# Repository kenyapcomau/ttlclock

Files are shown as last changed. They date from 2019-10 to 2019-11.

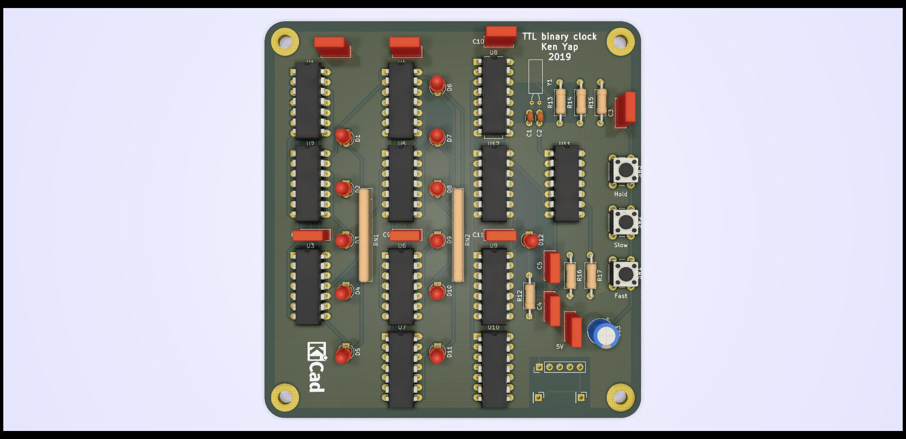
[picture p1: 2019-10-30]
ttlclock-raytraced.jpg

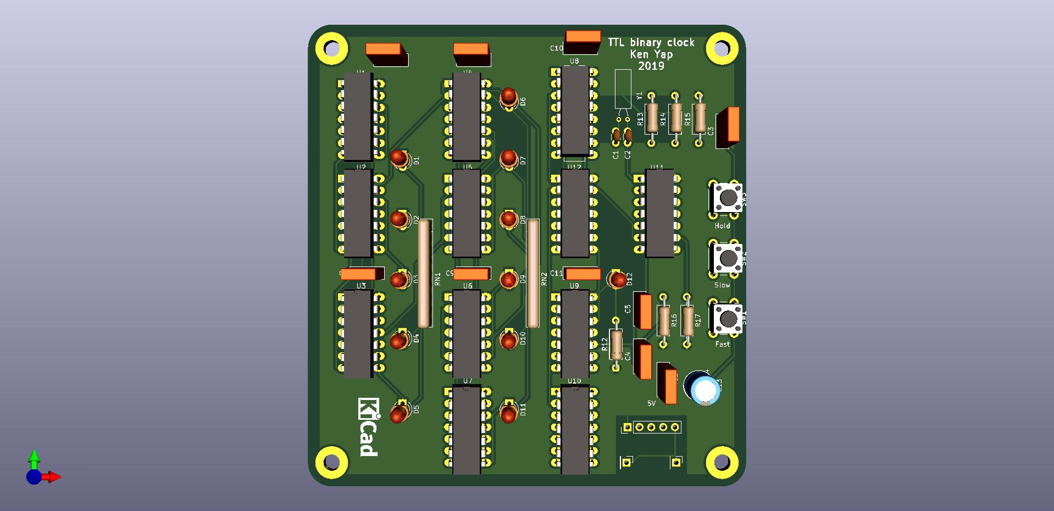
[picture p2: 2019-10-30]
ttlclock.jpg

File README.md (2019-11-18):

# TTL clock

These are the Kicad design files for the TTL clock described in my [Hackaday project](https://hackaday.io/project/168157-ttl-binary-clock)

## Versioning

First release November 2019

## Notes

Due to the 2 LS load fan out of the CD4060 (U8), you should use a 74LS50 (U12) and not a standard TTL package, otherwise the 1 Hz signal will be unreliable. Anyway non-LS parts are rare these days. LS is lower power consumption too.

## Authors

* **Ken Yap**

## License

See the [LICENSE](LICENSE.md) file for license rights and limitations (MIT).

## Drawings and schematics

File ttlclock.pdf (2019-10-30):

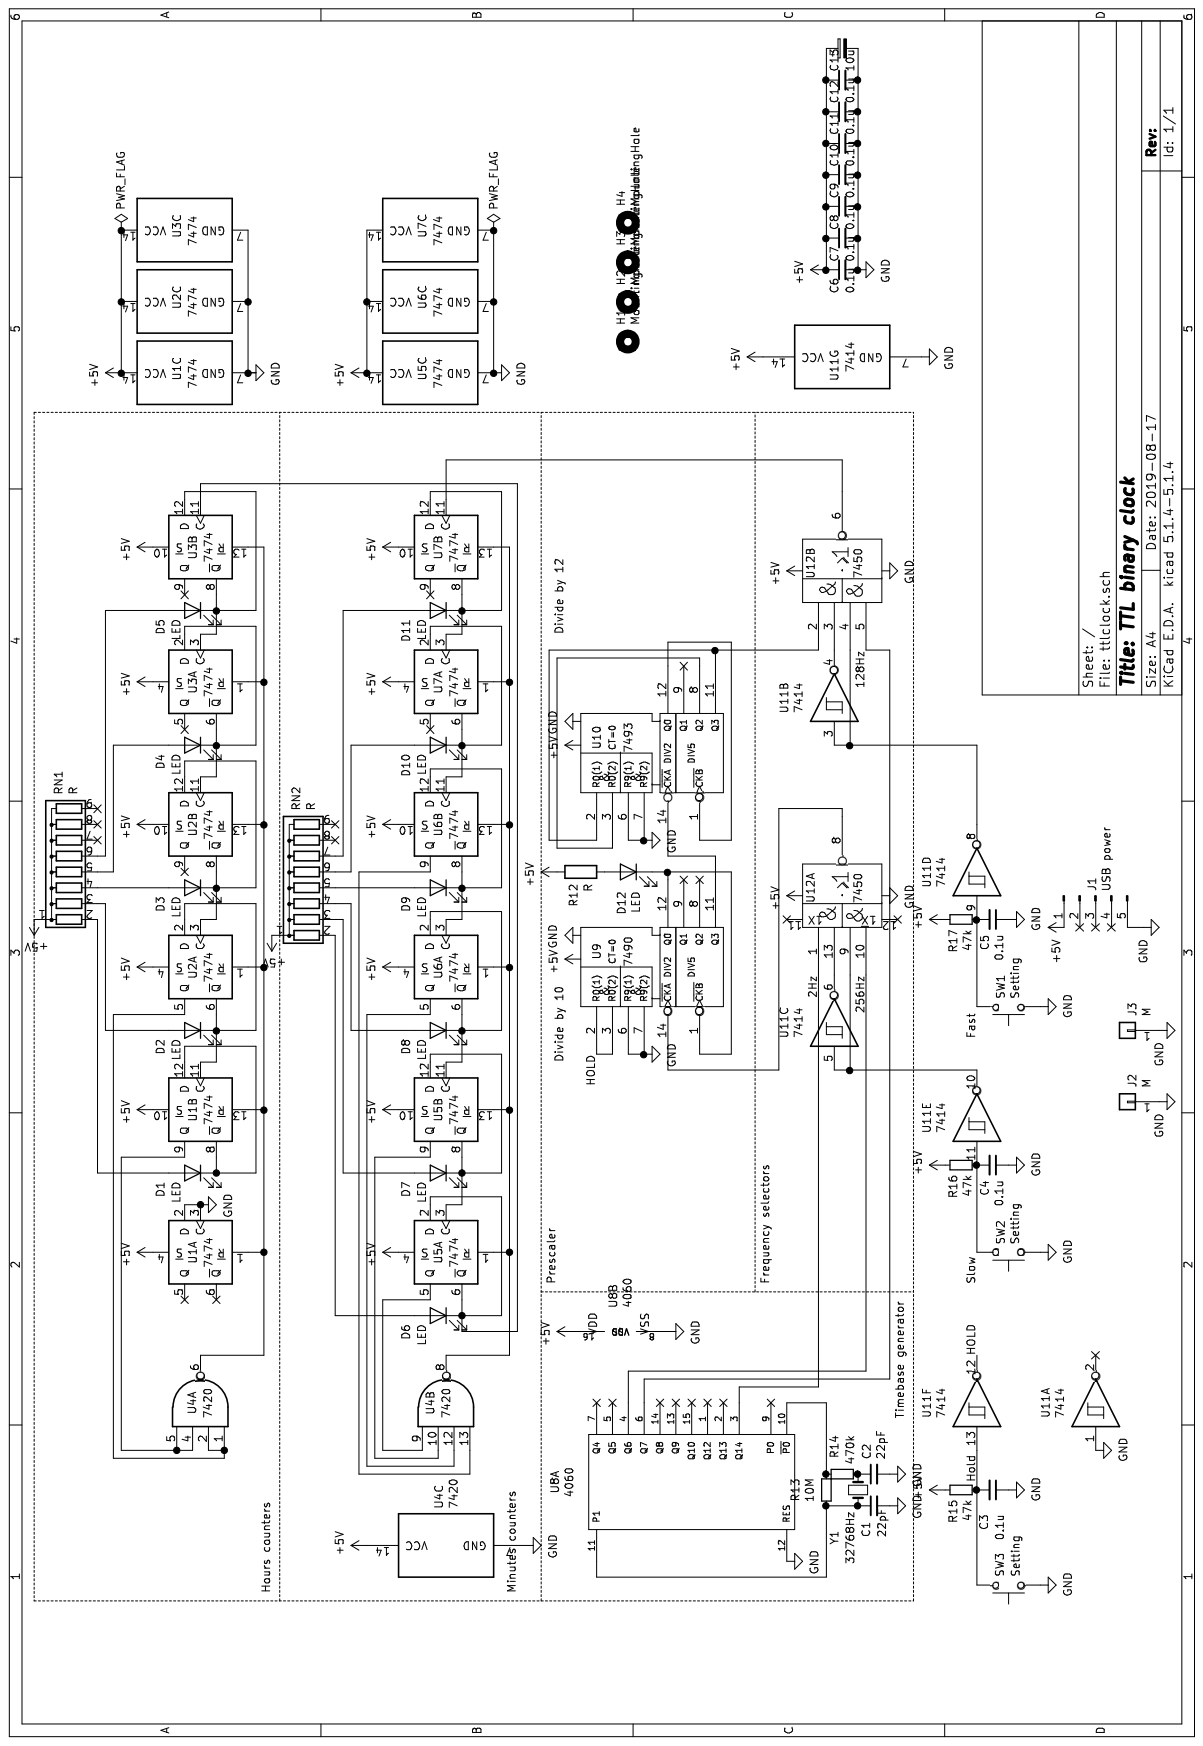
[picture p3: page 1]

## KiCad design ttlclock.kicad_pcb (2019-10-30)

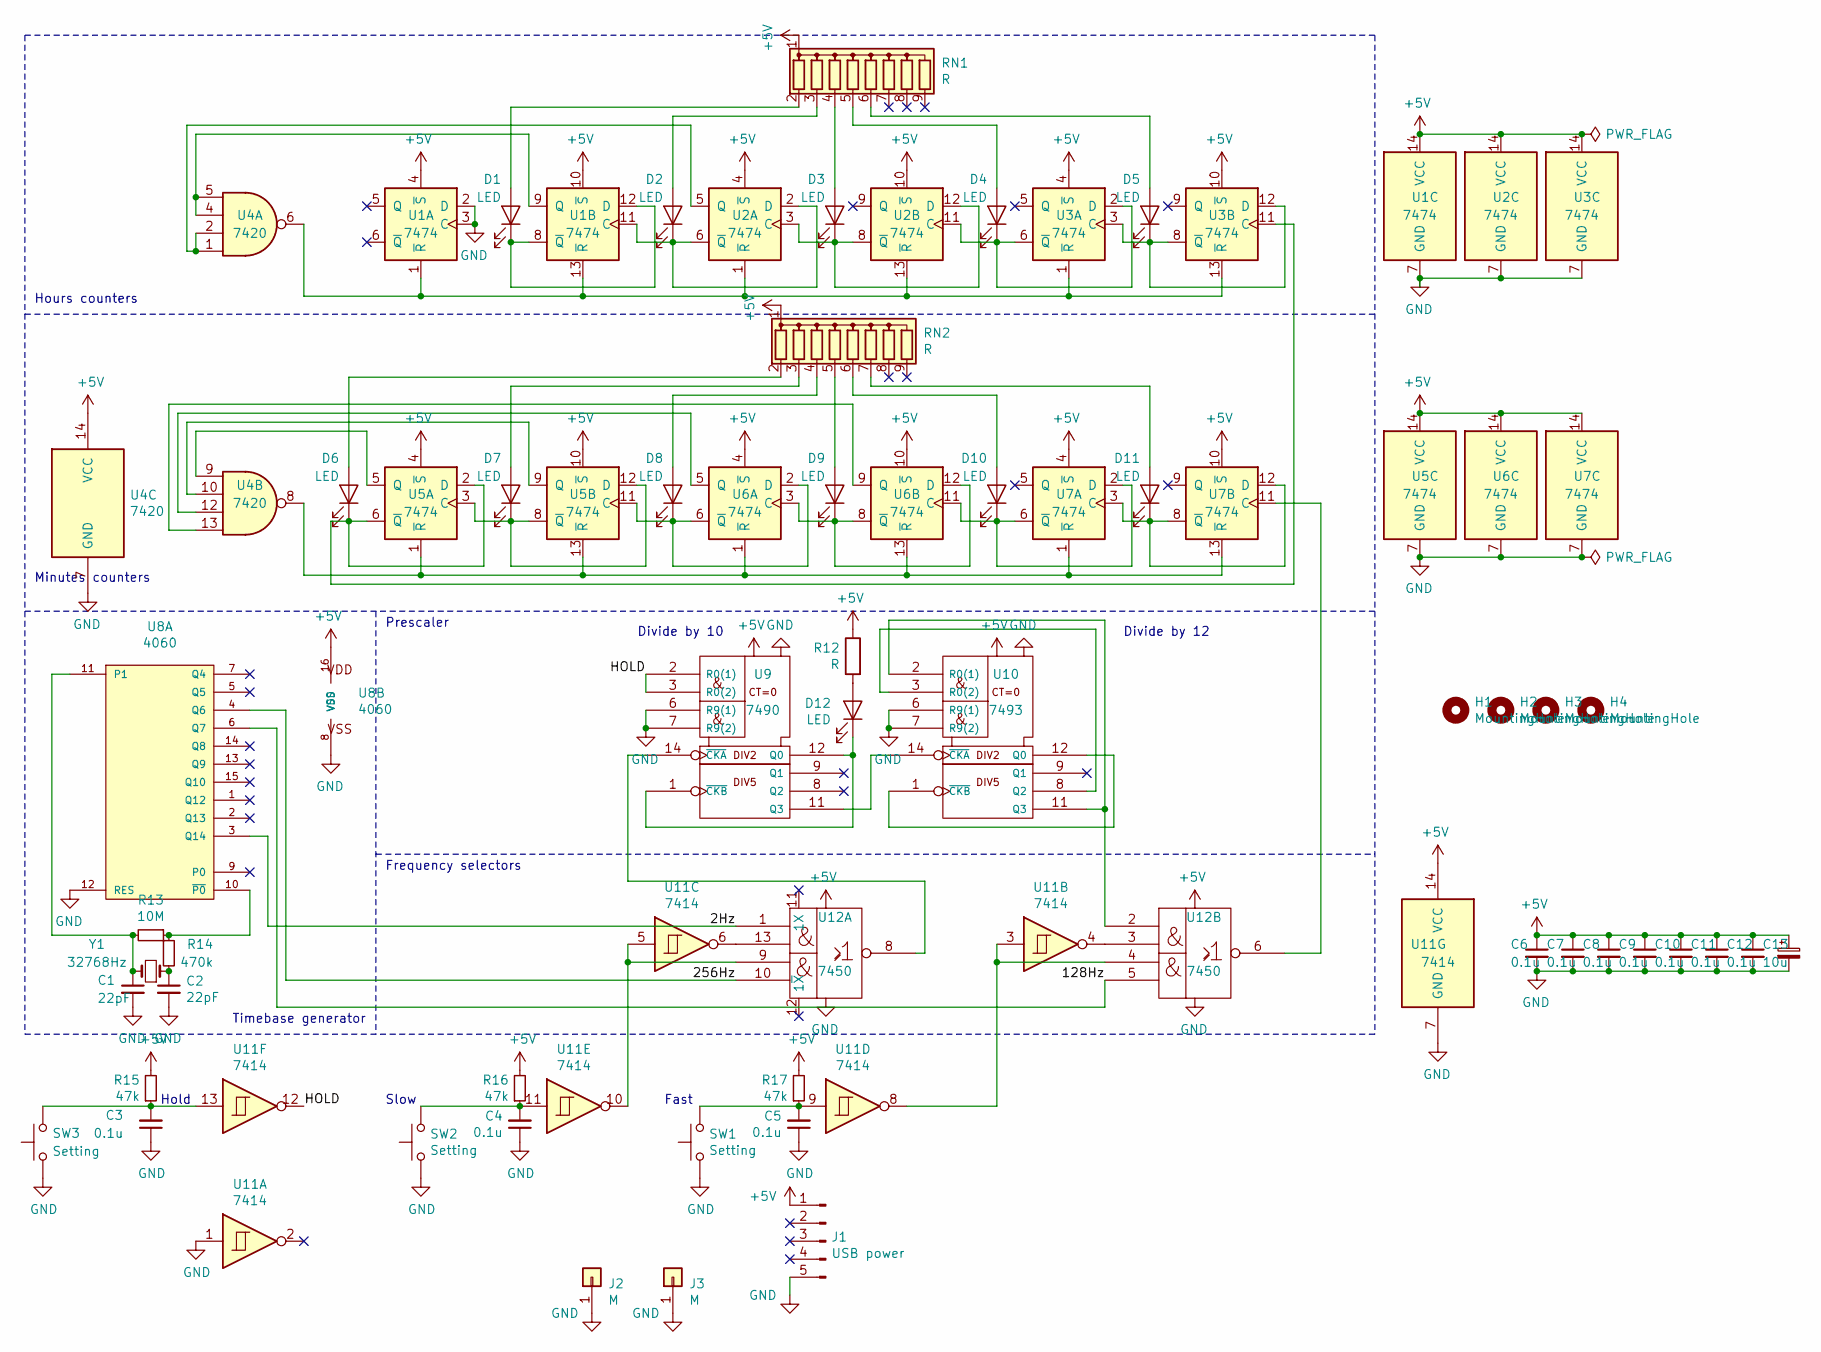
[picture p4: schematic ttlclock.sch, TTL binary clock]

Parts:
C1, C2: 22pF; C_Disc_D3.0mm_W1.6mm_P2.50mm
C3, C4, C5, C6, C7, C8, C9, C10, C11, C12: 0.1u; C_Rect_L7.2mm_W2.5mm_P5.00mm_FKS2_FKP2_MKS2_MKP2
C13: 10u; CP_Radial_D6.3mm_P2.50mm
D1, D2, D3, D4, D5, D6, D7, D8, D9, D10, D11, D12: LED; LED_D3.0mm
H1, H2, H3, H4: MountingHole; MountingHole_3.5mm_Pad
J1: USB power; PinHeader_1x05_P2.54mm_Vertical
J2, J3: M; PinHeader_1x01_P2.54mm_Vertical
R12: R; R_Axial_DIN0207_L6.3mm_D2.5mm_P10.16mm_Horizontal
R13: 10M; R_Axial_DIN0207_L6.3mm_D2.5mm_P10.16mm_Horizontal
R14: 470k; R_Axial_DIN0207_L6.3mm_D2.5mm_P10.16mm_Horizontal
R15, R16, R17: 47k; R_Axial_DIN0207_L6.3mm_D2.5mm_P10.16mm_Horizontal
RN1, RN2: R; R_Array_SIP9
SW1, SW2, SW3: Setting; SW_PUSH_6mm_H4.3mm
U1, U2, U3, U5, U6, U7: 7474; DIP-14_W7.62mm_LongPads
U4: 7420; DIP-14_W7.62mm_LongPads
U8: 4060; DIP-16_W7.62mm_LongPads
U9: 7490; DIP-14_W7.62mm_LongPads
U10: 7493; DIP-14_W7.62mm_LongPads
U11: 7414; DIP-14_W7.62mm_LongPads
U12: 7450; DIP-14_W7.62mm_LongPads
Y1: 32768Hz; Crystal_C38-LF_D3.0mm_L8.0mm_Horizontal

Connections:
+5V: C6.1, C7.1, C8.1, C9.1, C10.1, C11.1, C12.1, C13.1, J1.1, R12.1, R15.2, R16.2, R17.2, RN1.1 (common), RN2.1 (common), U1.4 (~S), U1.10 (~S), U1.14 (VCC), U2.4 (~S), U2.10 (~S), U2.14 (VCC), U3.4 (~S), U3.10 (~S), U3.14 (VCC), U4.14 (VCC), U5.4 (~S), U5.10 (~S), U5.14 (VCC), U6.4 (~S), U6.10 (~S), U6.14 (VCC), U7.4 (~S), U7.10 (~S), U7.14 (VCC), U8.16 (VDD), U9.5 (VCC), U10.5 (VCC), U11.14 (VCC), U12.14 (VCC)
/2Hz: U8.3 (Q14), U12.1
/128Hz: U8.6 (Q7), U12.5
/256Hz: U8.4 (Q6), U12.10
/HOLD: U9.2 (R0(1)), U9.3 (R0(2)), U11.12
GND: C1.2, C2.2, C3.1, C4.1, C5.1, C6.2, C7.2, C8.2, C9.2, C10.2, C11.2, C12.2, C13.2, J1.5, J2.1, J3.1, SW1.1, SW2.1, SW3.1, U1.2 (D), U1.3 (C), U1.7 (GND), U2.7 (GND), U3.7 (GND), U4.7 (GND), U5.7 (GND), U6.7 (GND), U7.7 (GND), U8.8 (VSS), U8.12 (RES), U9.6 (R9(1)), U9.7 (R9(2)), U9.10 (GND), U10.6 (R9(1)), U10.7 (R9(2)), U10.10 (GND), U11.1, U11.7 (GND), U12.7 (GND)
unnamed: C1.1, R13.2, U8.11 (P1), Y1.2
unnamed: C2.1, R14.2, Y1.1
unnamed: C3.2, R15.1, SW3.2, U11.13
unnamed: C4.2, R16.1, SW2.2, U11.11
unnamed: C5.2, R17.1, SW1.2, U11.9
unnamed: D1.1 (K), U1.8 (~Q), U1.12 (D)
unnamed: D1.2 (A), RN1.2 (R1)
unnamed: D2.1 (K), U1.11 (C), U2.2 (D), U2.6 (~Q)
unnamed: D2.2 (A), RN1.3 (R2)
unnamed: D3.1 (K), U2.3 (C), U2.8 (~Q), U2.12 (D)
unnamed: D3.2 (A), RN1.4 (R3)
unnamed: D4.1 (K), U2.11 (C), U3.2 (D), U3.6 (~Q)
unnamed: D4.2 (A), RN1.5 (R4)
unnamed: D5.1 (K), U3.3 (C), U3.8 (~Q), U3.12 (D)
unnamed: D5.2 (A), RN1.6 (R5)
unnamed: D6.1 (K), U3.11 (C), U5.2 (D), U5.6 (~Q)
unnamed: D6.2 (A), RN2.2 (R1)
unnamed: D7.1 (K), U5.3 (C), U5.8 (~Q), U5.12 (D)
unnamed: D7.2 (A), RN2.3 (R2)
unnamed: D8.1 (K), U5.11 (C), U6.2 (D), U6.6 (~Q)
unnamed: D8.2 (A), RN2.4 (R3)
unnamed: D9.1 (K), U6.3 (C), U6.8 (~Q), U6.12 (D)
unnamed: D9.2 (A), RN2.5 (R4)
unnamed: D10.1 (K), U6.11 (C), U7.2 (D), U7.6 (~Q)
unnamed: D10.2 (A), RN2.6 (R5)
unnamed: D11.1 (K), U7.3 (C), U7.8 (~Q), U7.12 (D)
unnamed: D11.2 (A), RN2.7 (R6)
unnamed: D12.1 (K), U9.1 (~CKB), U9.12 (Q0)
unnamed: D12.2 (A), R12.2
unnamed: R13.1, R14.1, U8.10 (~P0~)
unnamed: U1.1 (~R), U1.13 (~R), U2.1 (~R), U2.13 (~R), U3.1 (~R), U3.13 (~R), U4.6
unnamed: U1.9 (Q), U4.4, U4.5
unnamed: U2.5 (Q), U4.1, U4.2
unnamed: U4.8, U5.1 (~R), U5.13 (~R), U6.1 (~R), U6.13 (~R), U7.1 (~R), U7.13 (~R)
unnamed: U4.9, U5.5 (Q)
unnamed: U4.10, U5.9 (Q)
unnamed: U4.12, U6.5 (Q)
unnamed: U4.13, U6.9 (Q)
unnamed: U10.1 (~CKB), U10.12 (Q0)
unnamed: U10.3 (R0(2)), U10.8 (Q2)
unnamed: U10.2 (R0(1)), U10.11 (Q3), U12.2
unnamed: U9.11 (Q3), U10.14 (~CKA)
unnamed: U11.3, U11.8, U12.4
unnamed: U11.4, U12.3
unnamed: U11.6, U12.13
unnamed: U11.5, U11.10, U12.9
unnamed: U7.11 (C), U12.6
unnamed: U9.14 (~CKA), U12.8

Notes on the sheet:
Slow
Fast
Hold
Hours counters
Minutes counters
Timebase generator
Frequency selectors
Prescaler
Divide by 10
Divide by 12

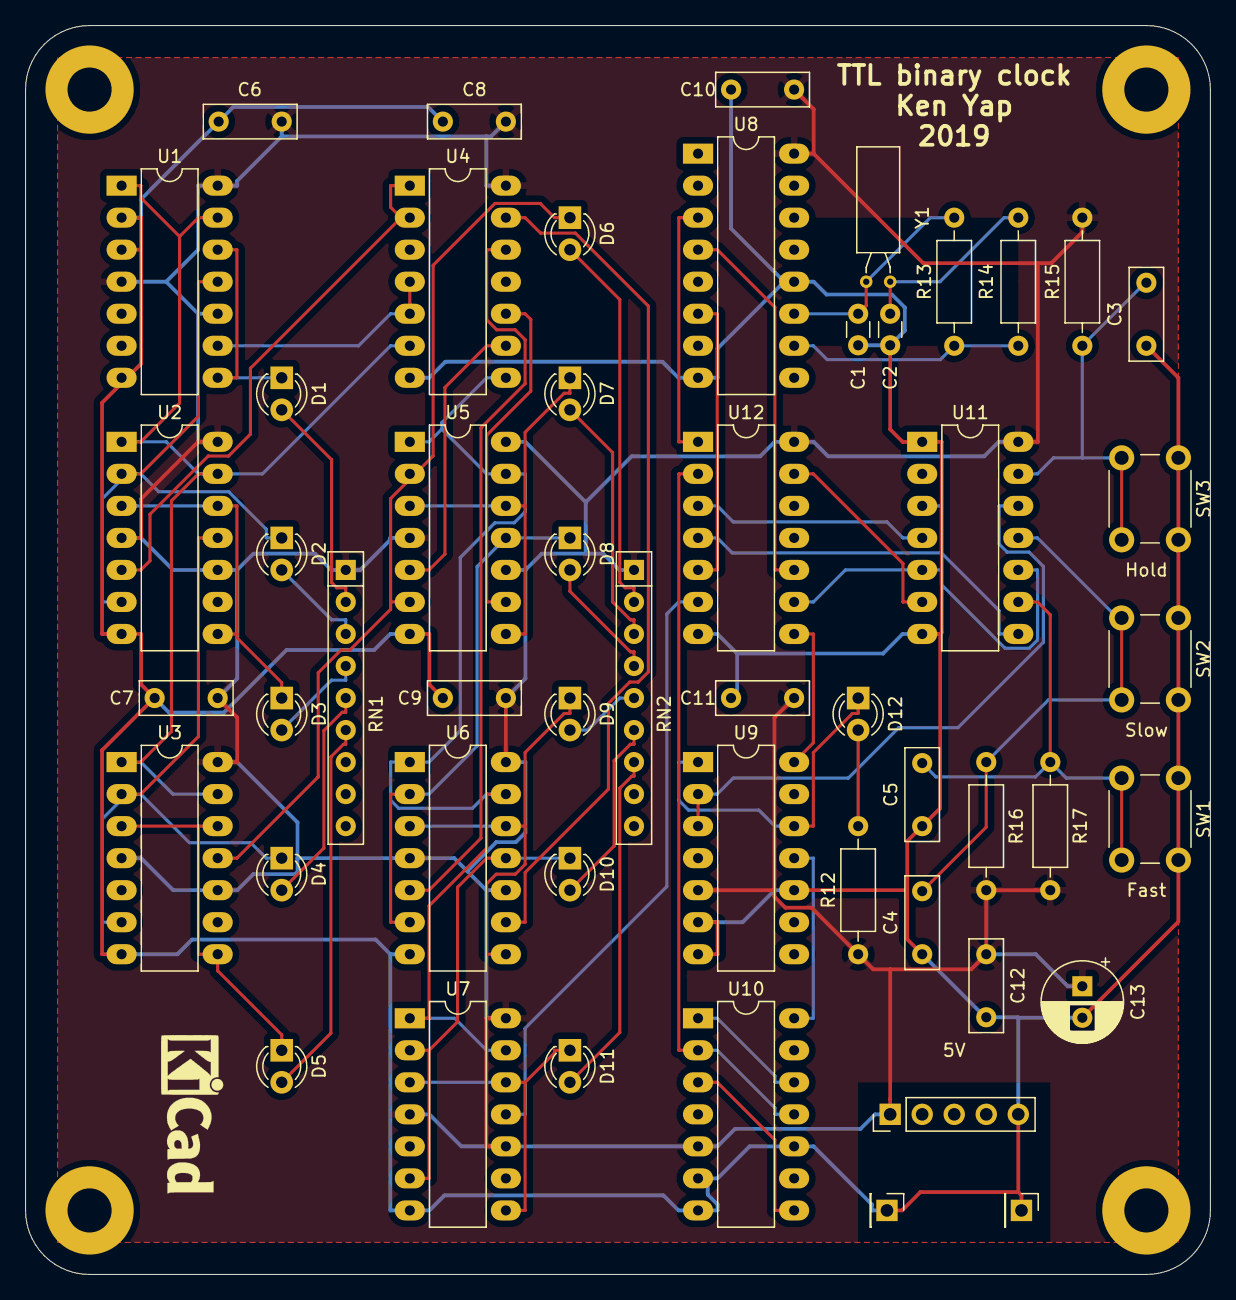
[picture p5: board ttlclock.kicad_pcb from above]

Board: 2 copper layers, 94.0 x 99.1 mm, 58 parts (1 on the bottom side), 54 nets.

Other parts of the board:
K1, K2: KiCad-Logo_5mm_SilkScreen
